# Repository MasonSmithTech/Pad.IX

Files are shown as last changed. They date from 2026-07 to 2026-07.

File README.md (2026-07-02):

# Pad.IX, a custom 9 key macropad

this project is a spot where the code, schematics, 3d models, and other files related to the Hack Club Stardance "HackPad" project are located, with my iteration named "Pad.IX" since it has nine keys. 

The Pad.IX is a nine key macro pad with an encoder and OLED screen, with future hopes of implementing VIA for custom keymapping.

MacroPadFull_2026-Jun-22_02-24-42AM-000_CustomizedView29703276037

## CAD
The case was modeled inside of OnShape (A new tool for me) and renders (as seen above) were created inside of fusion 360. The case features a top piece which holds the switches and pcb, and a bottom piece to protect the electronics, with the two parts being bolted together with M3 bolts and heat press inserts. 
The case was somewhat influenced by the OZO Keyboards Skeleton Keyboard Case, but mainly it is just an interesting looking open shell design that appeared in my brain on the bus home from school!



## PCB
the schematic and PCB are created using KiCad and LOTS of google.

schematic:



PCB:



## Firmware
This hackpad uses QMK firmware for everything.

the rotary encoder changes volume. press to mute
The 9 keys currently act as ma number pad
The OLED is a status display of sorts (mainly says "Pad.IX" tho)
Hopefully VIA support will be added once I actually build the thing irl

Thats pretty much it the firmware was pretty confusing to make so idk what to say

## Bill Of Materials 
    - 9x cherry MX switches
    - 9x DSA Keycaps (not required)
    - 1x 0.91" 128x32 OLED Display
    - 1x Seed XIAO RP2040
    - 1x EC11 Rotary Encoder
    - 1x Custom designed and manufactured pcb
    - 1x 3d printed top housing
    - 1x 3d printed bottom housing
    - 4x M3 heatpress inserts
    - 4x M3x16mm SHCS Bolts
    - 10x 1N4148 DO-35 Diodes

## Software
    - QMK MSYS
    - Fusion 360
    - KiCad 9.0    
    - Onshape
    - Visual Studio Code
    - File Explorer

## Author's Note
Thanks to the people at Hack Club this was an amazing experience! This is my first Hack Club build but I am looking forward to doing so much more in the future!
Also thanks to google cuz this was VERY confusing!

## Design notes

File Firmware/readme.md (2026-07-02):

# Pad.IX Firmware

A 9 key macro pad with an OLED screen and a knob

* Keyboard Maintainer: [MasonSmithTech](https://github.com/MasonSmithTech)
* Hardware Supported: *RP2040*
* Hardware Availability: *Amazon, Ebay, ALiExpress*

Make example for this keyboard (after setting up your build environment):

    make pad_ix_new:default

Flashing example for this keyboard:

    make pad_ix_new:default:flash

See the [build environment setup](https://docs.qmk.fm/#/getting_started_build_tools) and the [make instructions](https://docs.qmk.fm/#/getting_started_make_guide) for more information. Brand new to QMK? Start with our [Complete Newbs Guide](https://docs.qmk.fm/#/newbs).

## Bootloader

Enter the bootloader in 3 ways:

* **Bootmagic reset**: Hold down the key at (0,0) in the matrix (usually the top left key or Escape) and plug in the keyboard
* **Physical reset button**: Briefly press the button on the back of the PCB - some may have pads you must short instead
* **Keycode in layout**: Press the key mapped to `QK_BOOT` if it is available

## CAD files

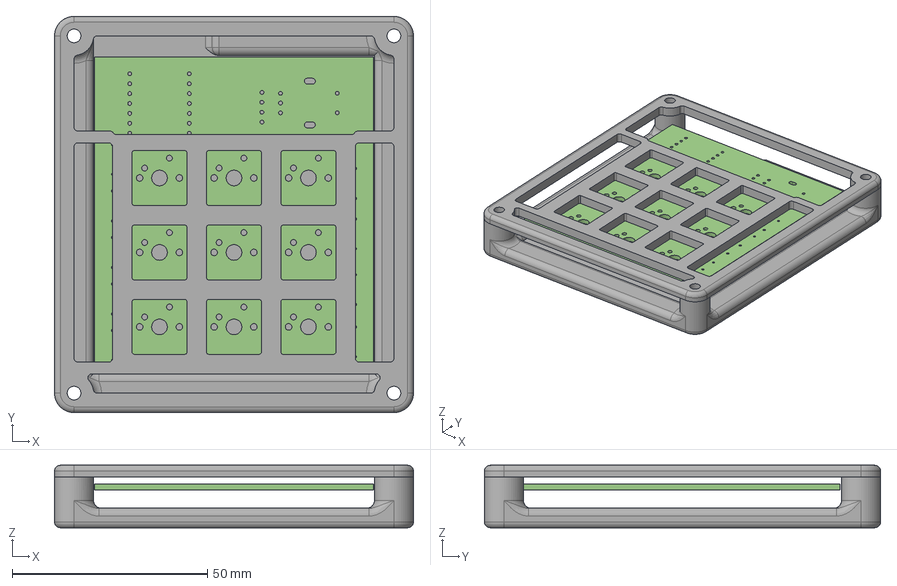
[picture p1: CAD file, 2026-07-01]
CAD/Pad_IX_Complete.step
91.8 x 101.4 x 16.0 mm
Bottom
HackPadJune_PCB
Top

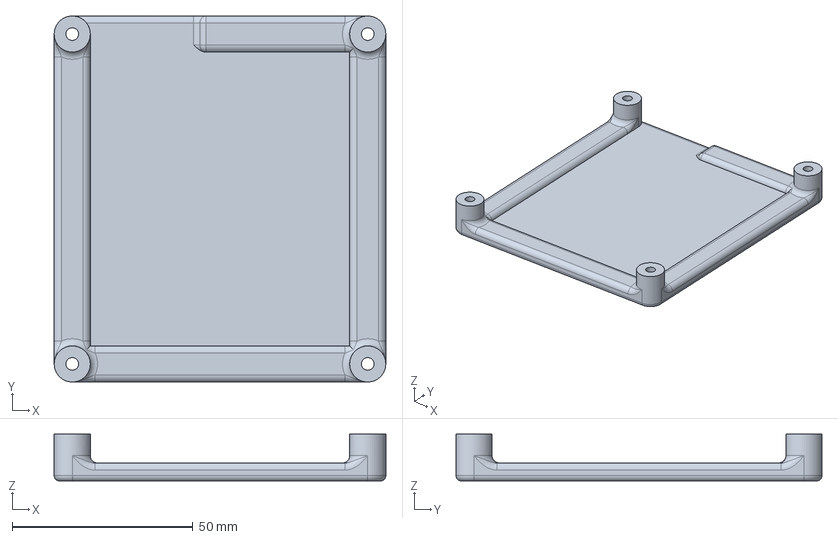
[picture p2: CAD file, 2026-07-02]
Production/Bottom.step
91.8 x 101.4 x 13.0 mm

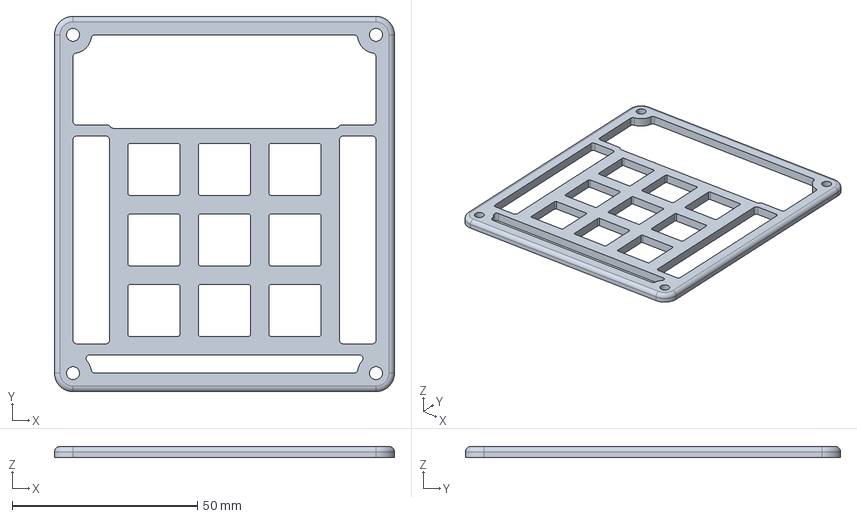
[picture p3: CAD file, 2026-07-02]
Production/Top.step
91.8 x 101.4 x 3.00 mm

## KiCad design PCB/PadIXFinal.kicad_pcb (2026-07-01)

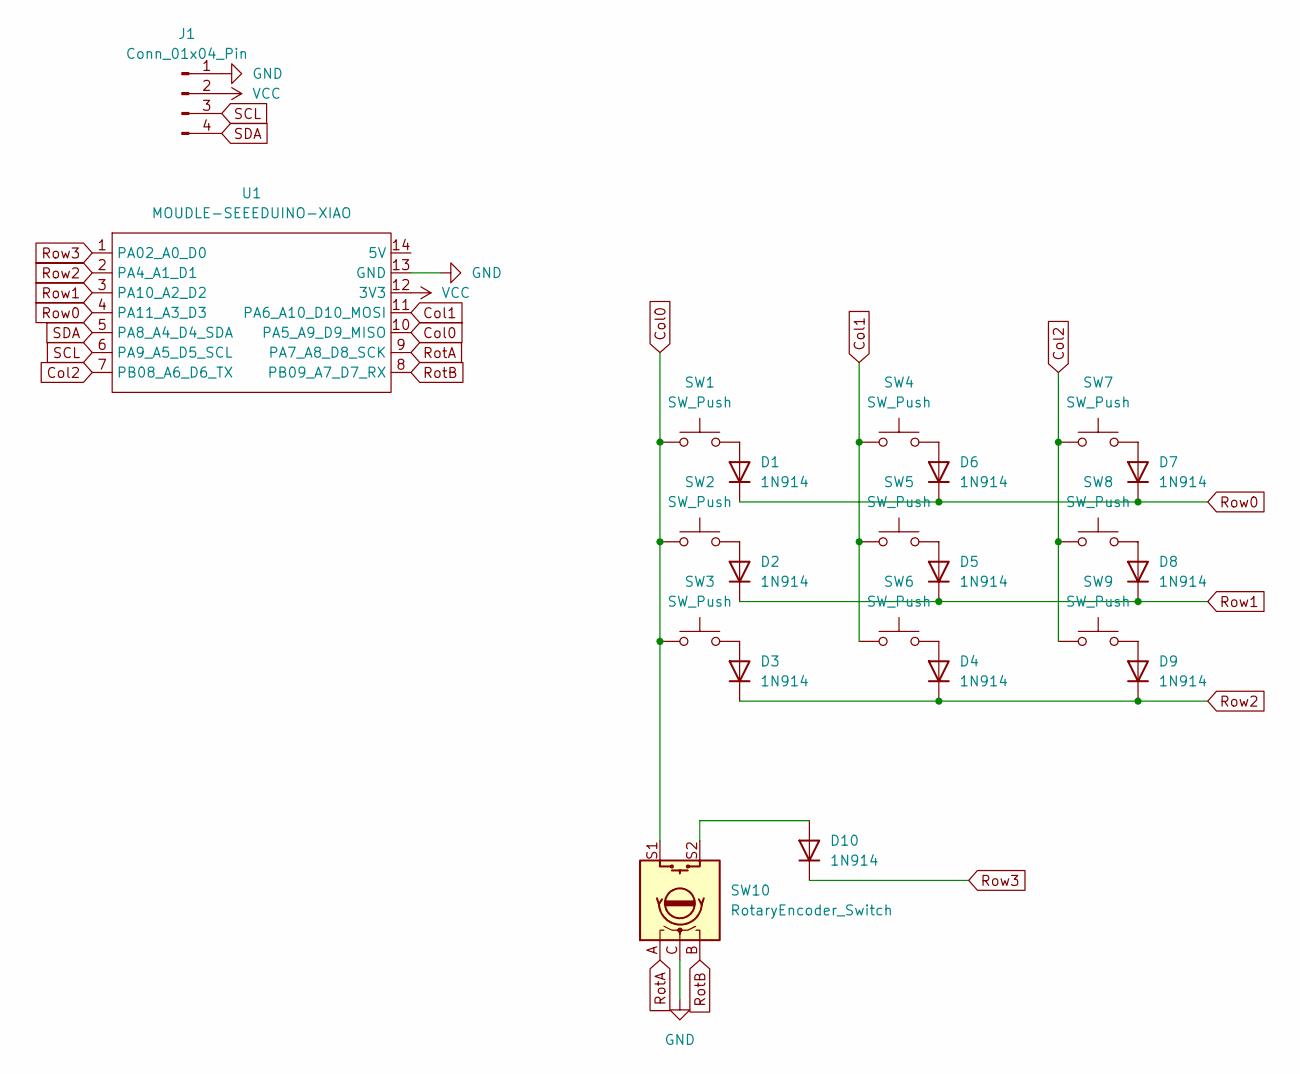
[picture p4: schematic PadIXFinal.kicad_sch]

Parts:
D1, D2, D3, D4, D5, D6, D7, D8, D9, D10: 1N914; D_DO-35_SOD27_P7.62mm_Horizontal
J1: Conn_01x04_Pin; PinHeader_1x04_P2.54mm_Vertical
SW1, SW2, SW3, SW4, SW5, SW6, SW7, SW8, SW9: SW_Push; SW_Cherry_MX_1.00u_PCB
SW10: RotaryEncoder_Switch; RotaryEncoder_Alps_EC11E-Switch_Vertical_H20mm
U1: MOUDLE-SEEEDUINO-XIAO; XIAO-Generic-Hybrid-14P-2.54-21X17.8MM

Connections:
Col1: SW4.1, SW5.1, SW6.1, U1.11 (PA6_A10_D10_MOSI)
Col2: SW7.1, SW8.1, SW9.1, U1.7 (PB08_A6_D6_TX)
GND: D10.2 (A), J1.1, SW10.C, SW10.S2, U1.13 (GND)
unnamed: D1.2 (A), SW1.2
unnamed: D2.2 (A), SW2.2
unnamed: D3.2 (A), SW3.2
unnamed: D4.2 (A), SW6.2
unnamed: D5.2 (A), SW5.2
unnamed: D6.2 (A), SW4.2
unnamed: D7.2 (A), SW7.2
unnamed: D8.2 (A), SW8.2
unnamed: D9.2 (A), SW9.2
RotA: SW10.A, U1.9 (PA7_A8_D8_SCK)
RotB: SW10.B, U1.8 (PB09_A7_D7_RX)
Row0: D1.1 (K), D6.1 (K), D7.1 (K), U1.4 (PA11_A3_D3)
Row1: D2.1 (K), D5.1 (K), D8.1 (K), U1.3 (PA10_A2_D2)
Row2: D3.1 (K), D4.1 (K), D9.1 (K), U1.2 (PA4_A1_D1)
SCL: J1.3, U1.6 (PA9_A5_D5_SCL)
SDA: J1.4, U1.5 (PA8_A4_D4_SDA)
VCC: J1.2, U1.12 (3V3)

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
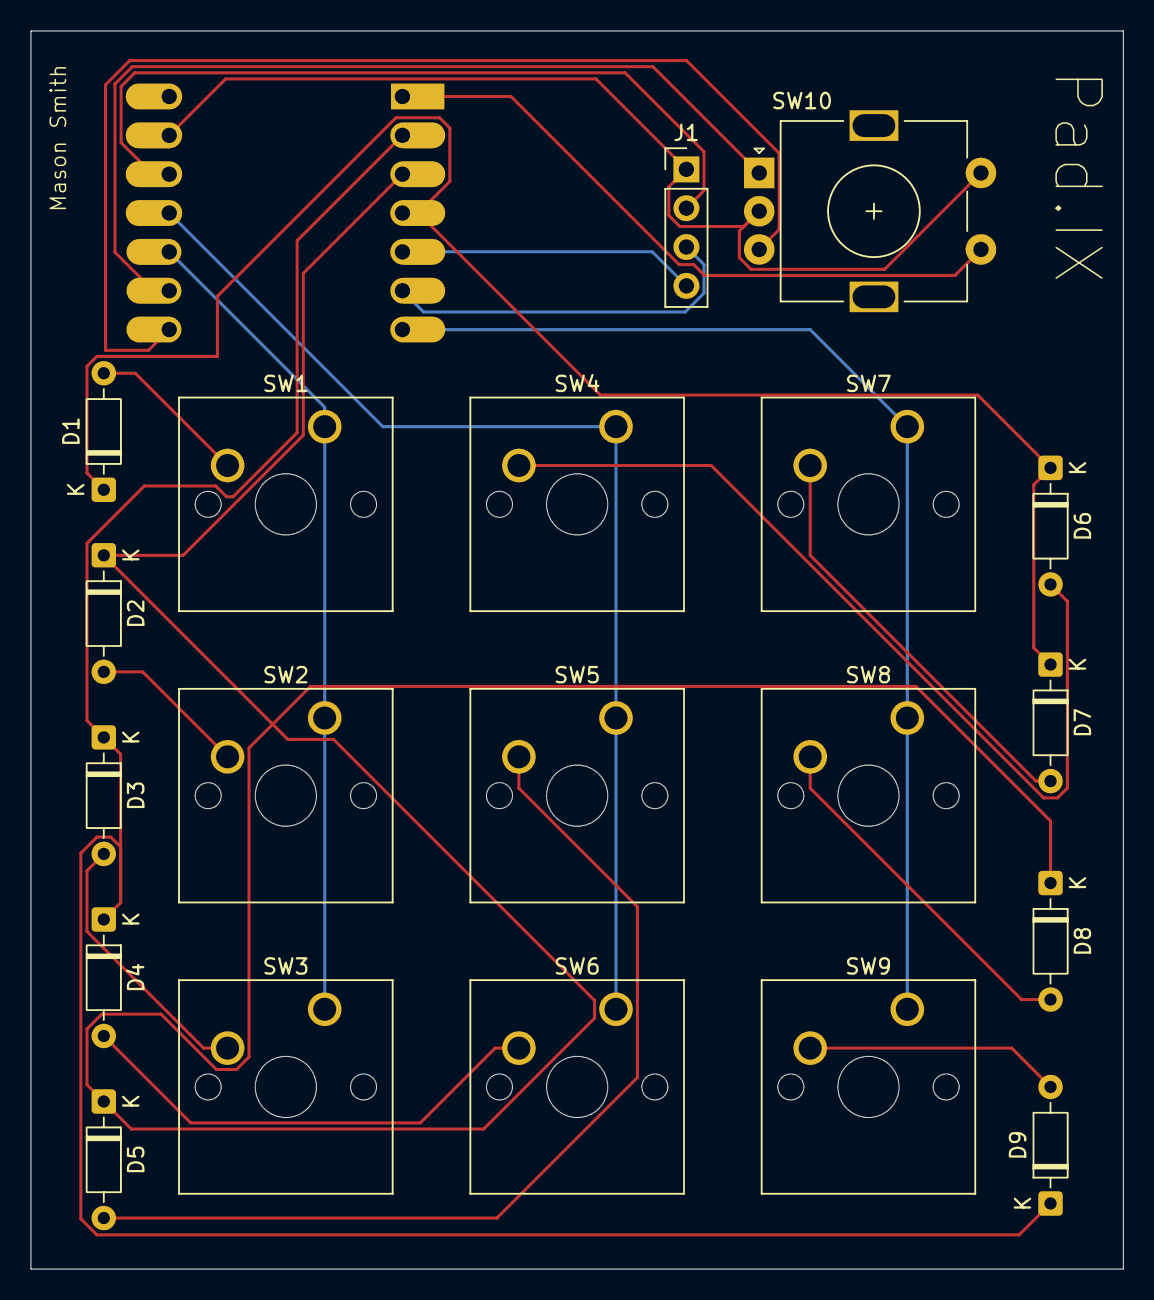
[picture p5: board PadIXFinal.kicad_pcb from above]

Board: 2 copper layers, 71.4 x 81.0 mm, 21 parts (1 on the bottom side), 22 nets.

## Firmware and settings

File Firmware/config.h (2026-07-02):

#pragma once

#define I2C_DRIVER I2CD1
#define I2C1_SDA_PIN GP5
#define I2C1_SCL_PIN GP6

#define OLED_DISPLAY_128X32
#define OLED_DISPLAY_ADDRESS 0x3C
#define OLED_TIMEOUT 300000

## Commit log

2026-07-01 Added 3d CAD Files of complete case
    [Pad_IX_Complete.step]
2026-07-01 Add temp67 to CAD/temp file
2026-07-01 Re-upload CAD Models
    [Pad_IX_Complete.step]
2026-07-01 KiCad Files Uploaded
    [PadIXFinal.kicad_pcb, PadIXFinal.kicad_sch]
2026-07-01 added PCB gerber
2026-07-01 case files
    [Bottom.step, Top.step]
2026-07-02 Revise project description and add PCB section
    Updated description to reflect future VIA implementation and added PCB section with schematic details.
2026-07-02 Update PCB image dimensions in README.md
2026-07-02 Add schematic and PCB images to README
    Added images for schematic and PCB in README.
2026-07-02 Add CAD section to README
    Added CAD section detailing case modeling and design influences.
2026-07-02 Enhance README with image and PCB details
    Added an image to the CAD section and improved PCB description.
2026-07-02 Update Bill Of Materials for clarity
    Clarified that DSA Keycaps are not required and removed extra period from diode list.
